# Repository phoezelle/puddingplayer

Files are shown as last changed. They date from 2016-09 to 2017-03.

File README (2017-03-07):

penser à :
passer en azerty + partage ram + …
  raspi-config
ctreate root passwd and log root
  sudo passwd root
update and upgrade apt-get
  apt-get clean
  apt-get update
  apt-get upgrade
install screen
  apt-get screen
install openframworks + script : dependancies.sh + scripts : codecs.sh
  cd /home/pi
  wget http://openframeworks.cc/versions/v0.9.3/of_v0.9.3_linuxarmv6l_release.tar.gz
  mkdir openFrameworks
  tar vxfz of_v0.9.3_linuxarmv6l_release.tar.gz -C openFrameworks --strip-components 1
  cd /home/pi/openFrameworks/scripts/linux/debian
  ./install_dependencies.sh
  ./install_codecs.sh
install wiringpi
  apt-get install wiringPi
install RF24
  $ mkdir nrf24l01
  $ cd nrf24l01
  $ git clone https://github.com/TMRh20/RF24.git
  $ cd RF24
  $ make
  $ sudo make install
compil openframeworks
  make Release -j4 -C /home/pi/openFrameworks/libs/openFrameworksCompiled/project
add my ssh key
  (on my terminal) ssh-copy-id pi@X.X.X.X (IP of pi)
install git-core and clone git repo
  apt-get install git-core
  cd /home/pi/openFrameworks/apps/myApps/
  git clone https://github.com/phoezelle/puddingplayer.git puddingplayer
compil project
  cd puddingplayer/
  make -j4
test it in screen attach mode
  screen -S pudding -m  /home/pi/openFrameworks/apps/myApps/puddingplayer/bin/puddingplayer
create init script
  nano /etc/init.d/puddingplayer
  chmod +x /etc/init.d/puddingplayer
create call script
  nano /etc/init.d/composecall
  chmod +x /etc/init.d/composecall
add call to the script in rc.local
  nano /etc/rc.local
hdmi auto hot plug
  nano /boot/config.txt
définir un réseau de secours
    nano /etc/wpa_supplicant/wpa_supplicant.conf
disable screen saver
    nano /etc/kbd/config
permit root login
    sudo nano /etc/ssh/sshd_config
active spi (dtparam=spi=on)
    sudo nano /boot/config.txt

passer en lecture seule le pi
  http://blog.pi3g.com/2014/04/make-raspbian-system-read-only/

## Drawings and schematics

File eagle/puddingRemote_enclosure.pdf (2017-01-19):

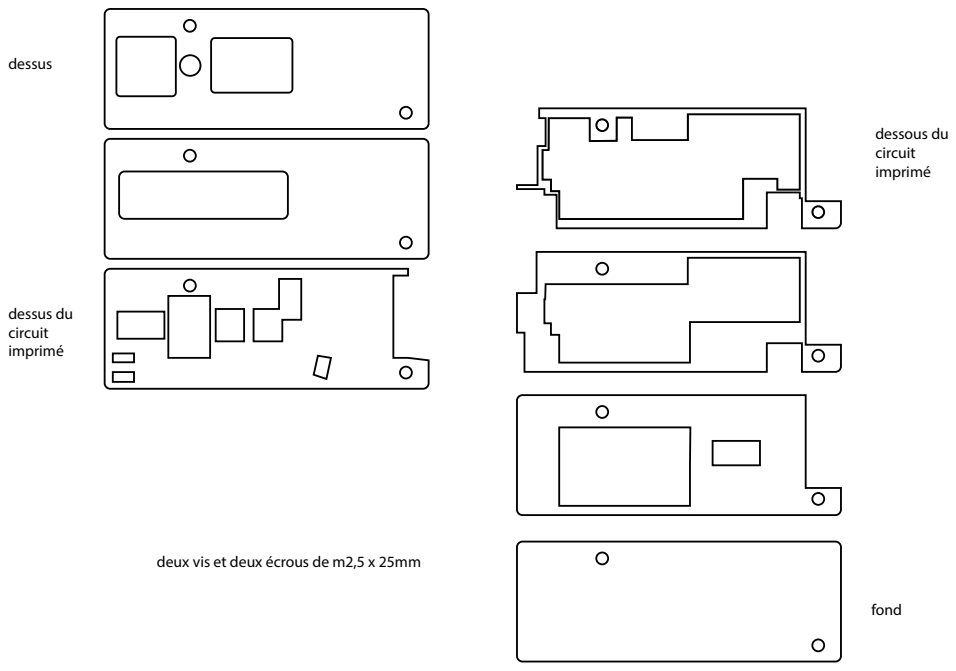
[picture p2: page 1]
dessus; fond; dessus du circuit imprimé; dessous du circuit imprimé

deux vis et deux écrous de m2,5 x 25mm

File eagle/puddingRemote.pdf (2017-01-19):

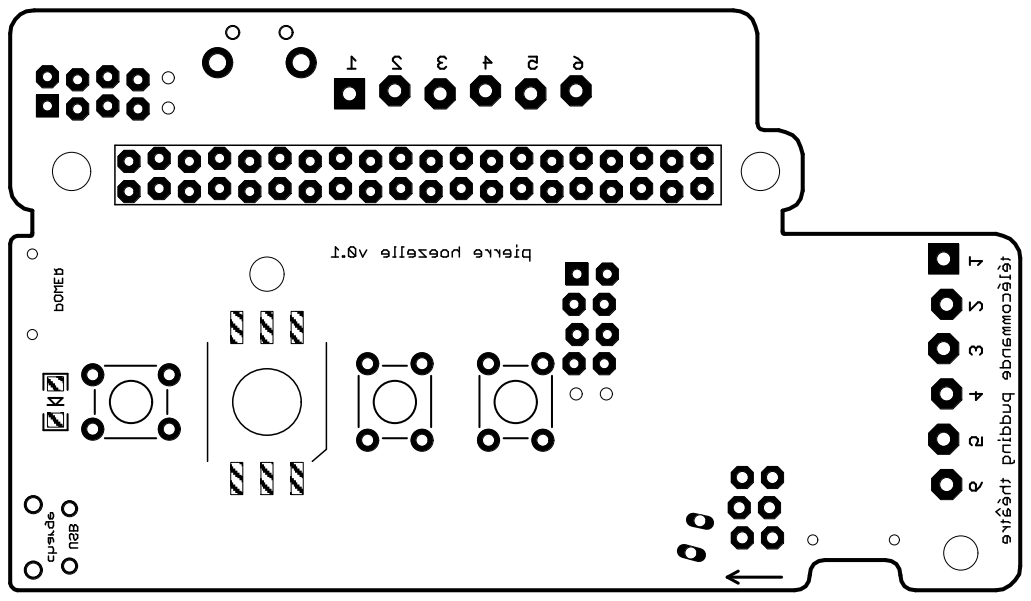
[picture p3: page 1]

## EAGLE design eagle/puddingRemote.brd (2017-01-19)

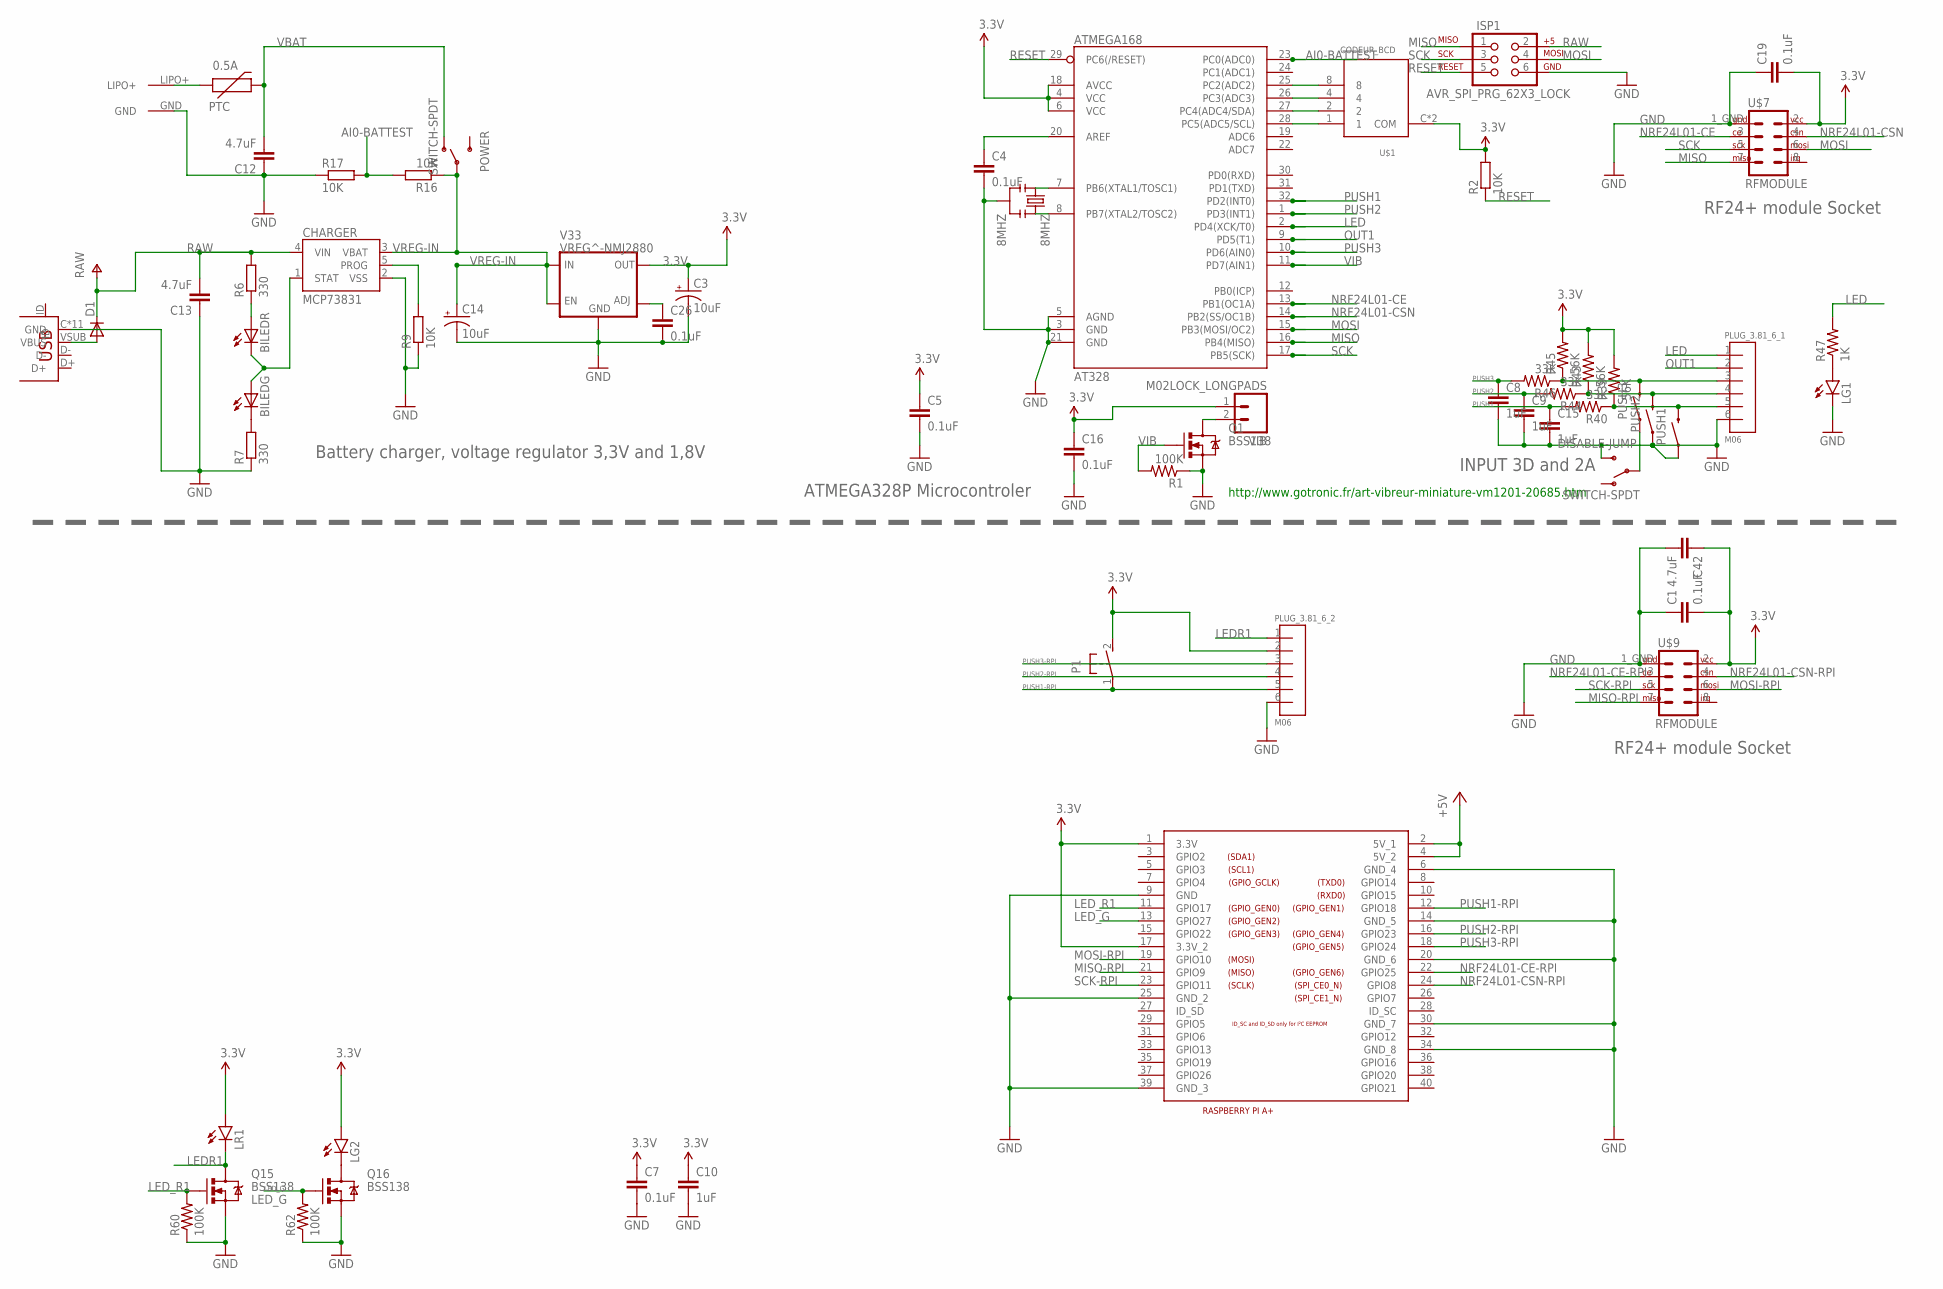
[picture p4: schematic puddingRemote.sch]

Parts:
0.5A: PTC; PTC-1210
8MHZ: 8MHZ; RESONATOR-SMD
AT328: ATMEGA168; TQFP32-08
BILED: BILED; 2XLED
C1, C4, C5, C7, C16, C19, C26: 0.1uF; C0603
C3, C14: 10uF; EIA3216
C8, C9, C10, C15: 1uF; C0603
C12, C13, C42: 4.7uF; C0603
CHARGER: MCP73831; SOT23-5
D1: DIODESMA-KIT; SMA-DIODE-KIT
DISABLE-JUMP: SWITCH-SPDT; SWITCH-102011SAQN
ISP1: AVR_SPI_PRG_62X3_LOCK; 2X3_LOCK
LG1, LG2: LED1206; LED-1206
LR1: LED1206; LED-1206
P1: 31-XX; B3F-31XX
PLUG_3.81_6_1, PLUG_3.81_6_2: M06; PLUG_06
POWER: SWITCH-SPDT; SWITCH-102011SAQN
PUSH1, PUSH2, PUSH3: SWITCH-MOMENTARY-2PTH; TACTILE-PTH
Q1, Q15, Q16: BSS138; SOT23-3
R1, R60, R62: 100K; 0603-RES
R2, R9, R16, R17: 10K; R0603
R6, R7: 330; R0603
R39, R43, R45: 56K; 0603-RES
R40, R44, R46: 33K; 0603-RES
R47: 1K; 0603-RES
U$1: CODEUR_BCD; MCRM4HAF-10R-V-B
U$2: USB-MICROB; USB-MICROB-10103594-0001LF
U$4: RASPIRASPIB; RASPIB
U$7, U$9: RFMODULE; 2X5_RFMODULE
U$8: LIPO_PAD; 2X1_LIPO_PAD
V33: VREG^-NMJ2880; SOT-89
VIB: M02LOCK_LONGPADS; 1X02_LOCK_LONGPADS

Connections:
1: AT328.28 (PC5(ADC5/SCL)), U$1.1
2: AT328.27 (PC4(ADC4/SDA)), U$1.2
3.3V: AT328.4 (VCC), AT328.6 (VCC), AT328.18 (AVCC), C1.2, C3.A (+), C5.1, C7.1, C10.1, C16.1, C19.2, C42.1, LG2.A, LR1.A, P1.2 (S), PLUG_3.81_6_2.2, R2.2, R39.2, R43.2, R45.2, U$1.C (COM), U$1.C2 (COM), U$4.1 (3.3V), U$4.17 (3.3V_2), U$7.2 (VCC), U$9.2 (VCC), V33.4 (OUT), VIB.1
4: AT328.26 (PC3(ADC3)), U$1.4
8: AT328.25 (PC2(ADC2)), U$1.8
+5V: U$4.2 (5V_1), U$4.4 (5V_2)
AI0-BATTEST: AT328.23 (PC0(ADC0)), R16.2, R17.2
AREF: AT328.20 (AREF), C4.1
GND: 8MHZ.2, AT328.3 (GND), AT328.5 (AGND), AT328.21 (GND), C1.1, C3.C (-), C4.2, C5.2, C7.2, C8.2, C9.2, C10.2, C12.1, C13.1, C14.C (-), C15.2, C16.2, C19.1, C26.2, C42.2, CHARGER.2 (VSS), DISABLE-JUMP.3 (S), ISP1.6, LG1.C, PLUG_3.81_6_1.6, PLUG_3.81_6_2.6, PUSH1.1, PUSH2.1, Q1.2 (S), Q15.2 (S), Q16.2 (S), R1.1, R7.1, R9.1, R17.1, R60.1, R62.1, U$2.C (GND), U$2.C1 (GND), U$2.C3 (GND), U$2.C4 (GND), U$2.C5 (GND), U$2.C6 (GND), U$2.GND, U$2.P$1 (GND), U$2.P$2 (GND), U$2.P$3 (GND), U$2.P$4 (GND), U$4.6 (GND_4), U$4.9 (GND), U$4.14 (GND_5), U$4.20 (GND_6), U$4.25 (GND_2), U$4.30 (GND_7), U$4.34 (GND_8), U$4.39 (GND_3), U$7.1_GND (GND), U$8.GND, U$9.1_GND (GND), V33.2 (GND)
LED: AT328.2 (PD4(XCK/T0)), PLUG_3.81_6_1.1, R47.2
LEDR1: LR1.C, PLUG_3.81_6_2.1, Q15.3 (D)
LED_G: Q16.1 (G), R62.2, U$4.13 (GPIO27)
LED_R1: Q15.1 (G), R60.2, U$4.11 (GPIO17)
LG1: LG2.C, Q16.3 (D)
MISO: AT328.16 (PB4(MISO)), ISP1.1, U$7.7 (MISO)
MISO-RPI: U$4.21 (GPIO9), U$9.7 (MISO)
MOSI: AT328.15 (PB3(MOSI/OC2)), ISP1.4, U$7.6 (MOSI)
MOSI-RPI: U$4.19 (GPIO10), U$9.6 (MOSI)
unnamed: C26.1, V33.3 (ADJ)
unnamed: D1.A, U$2.VSUB (VBUS)
unnamed: Q1.3 (D), VIB.2
unnamed: 8MHZ.1, AT328.7 (PB6(XTAL1/TOSC1))
unnamed: 8MHZ.3, AT328.8 (PB7(XTAL2/TOSC2))
unnamed: LG1.A, R47.1
unnamed: DISABLE-JUMP.C, PUSH3.1
unnamed: BILED.A2 (A), R6.1
unnamed: BILED.C3 (C), R7.2
unnamed: CHARGER.5 (PROG), R9.2
NRF24L01-CE: AT328.13 (PB1(OC1A)), U$7.3 (CE)
NRF24L01-CE-RPI: U$4.22 (GPIO25), U$9.3 (CE)
NRF24L01-CSN: AT328.14 (PB2(SS/OC1B)), U$7.4 (CSN)
NRF24L01-CSN-RPI: U$4.24 (GPIO8), U$9.4 (CSN)
OUT1: AT328.9 (PD5(T1)), PLUG_3.81_6_1.2
PUSH1: AT328.32 (PD2(INT0)), C15.1, R40.2
PUSH1-RPI: P1.1, PLUG_3.81_6_2.5, U$4.12 (GPIO18)
PUSH2: AT328.1 (PD3(INT1)), C9.1, R44.2
PUSH2-RPI: PLUG_3.81_6_2.4, U$4.16 (GPIO23)
PUSH3: AT328.10 (PD6(AIN0)), C8.1, R46.2
PUSH3-RPI: PLUG_3.81_6_2.3, U$4.18 (GPIO24)
RAW: C13.2, CHARGER.4 (VIN), D1.C, ISP1.2, R6.2
RESET: AT328.29 (PC6(/RESET)), ISP1.5, R2.1
S1: PLUG_3.81_6_1.5, PUSH1.3 (2), R39.1, R40.1
S2: PLUG_3.81_6_1.4, PUSH2.3 (2), R43.1, R44.1
S3: PLUG_3.81_6_1.3, PUSH3.3 (2), R45.1, R46.1
SCK: AT328.17 (PB5(SCK)), ISP1.3, U$7.5 (SCK)
SCK-RPI: U$4.23 (GPIO11), U$9.5 (SCK)
STAT: BILED.A1 (A), BILED.C4 (C), CHARGER.1 (STAT)
VBAT: 0.5A.2, C12.2, POWER.1 (O)
VBAT-RAW: 0.5A.1, U$8.LIPO+
VIB: AT328.11 (PD7(AIN1)), Q1.1 (G), R1.2
VREG-IN: C14.A (+), CHARGER.3 (VBAT), POWER.C, R16.1, V33.1 (EN), V33.5 (IN)

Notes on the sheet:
RF24+ module Socket
Battery charger, voltage regulator 3,3V and 1,8V
INPUT 3D and 2A
http://www.gotronic.fr/art-vibreur-miniature-vm1201-20685.htm
ATMEGA328P Microcontroler

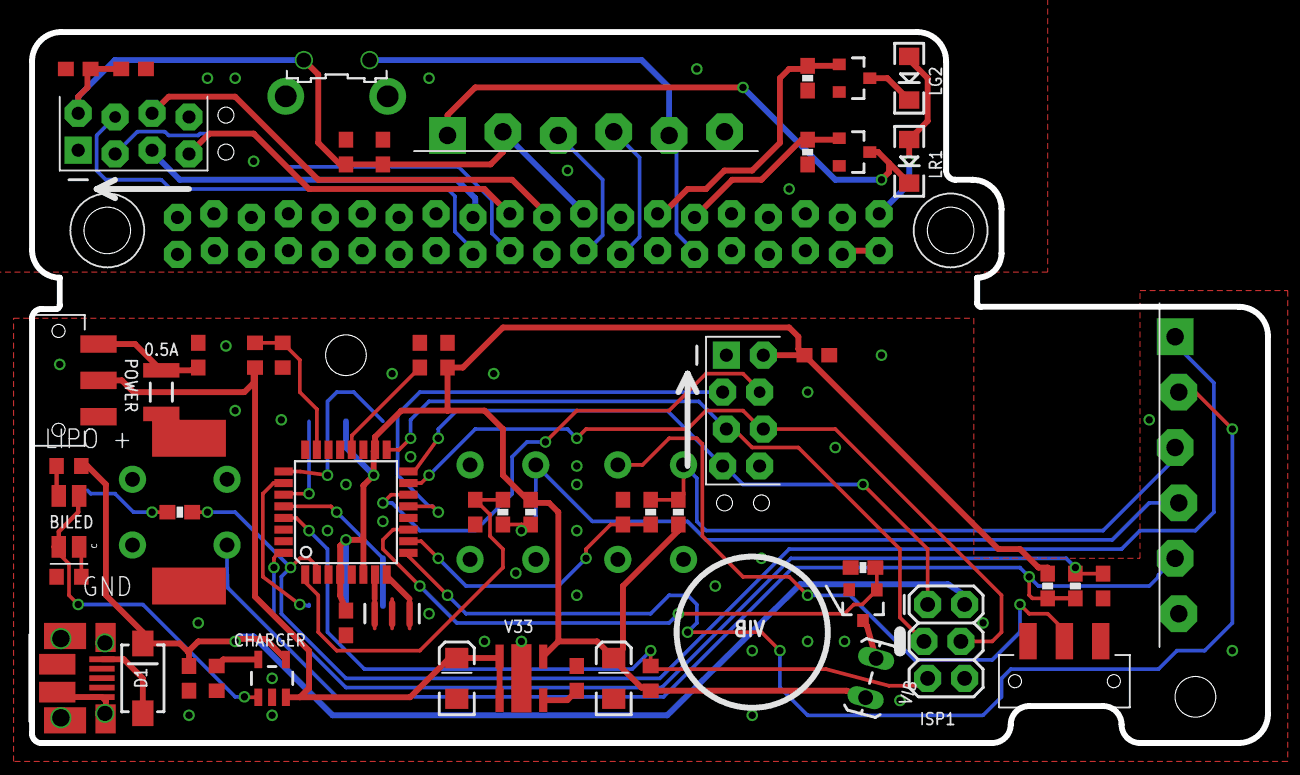
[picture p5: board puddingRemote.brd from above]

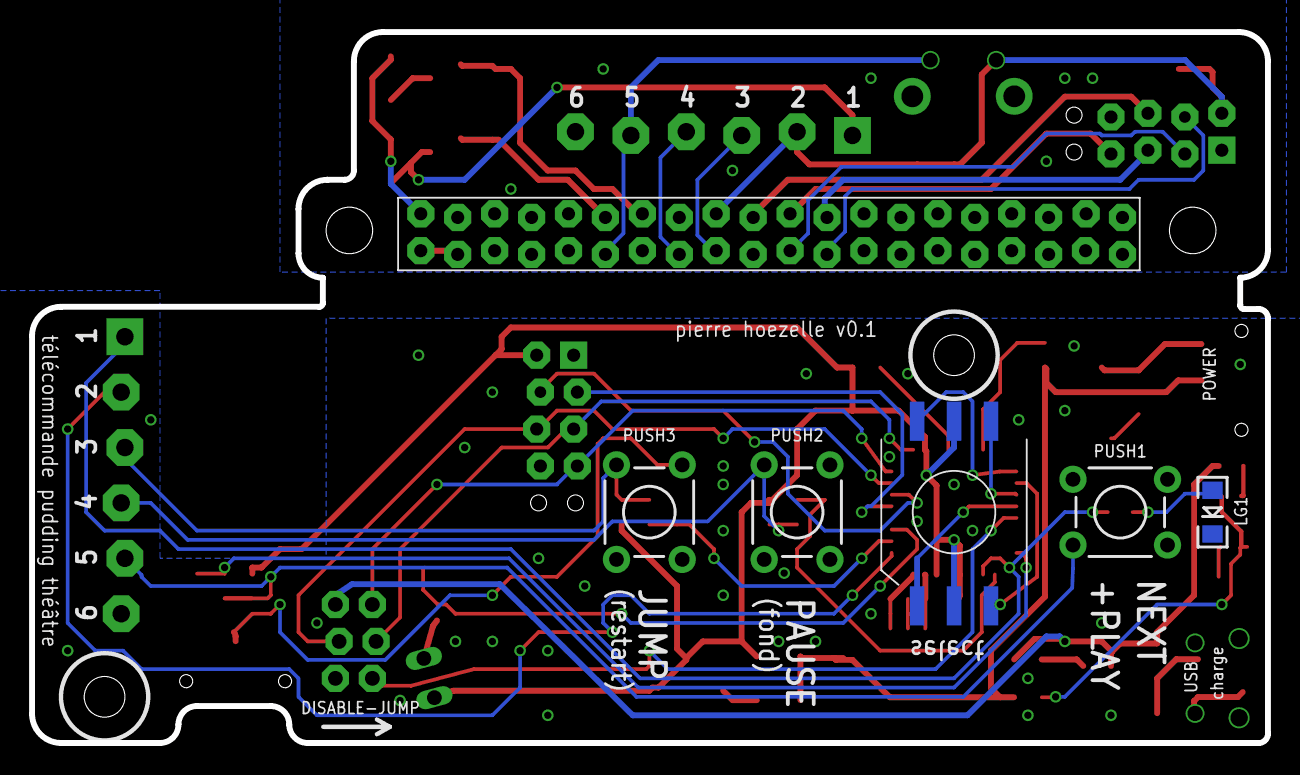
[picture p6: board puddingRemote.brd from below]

Board: 2 copper layers, 85.0 x 48.9 mm, 61 parts (6 on the bottom side), 51 nets.

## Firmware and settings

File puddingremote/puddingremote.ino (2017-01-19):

#include <stddef.h>
#include <avr/pgmspace.h>

#include "nRF24L01.h"
#include "RF24.h"
#include <SPI.h>

#define LED 4
#define VIB 7
#define PUSH1 2
#define PUSH2 3
#define PUSH3 6
#define OUT 5
#define RF24_CE 9
#define RF24_CSN 10
#define MOSI 11
#define MISO 12
#define CLK 13

byte codepin[4]={A2,A3,A4,A5};
byte codevalue[4]={8,4,2,1};


//BATTERY ANALOG CORECTION
#define MASTER_ABATT_5 598
#define MASTER_ABATT_4 589
#define MASTER_ABATT_3 580
#define MASTER_ABATT_2 577
#define MASTER_ABATT_1 564
#define MASTER_ABATT_OFF 540

#define CODE_ACK_WAITING 3
#define CODE_ACK_OK 9
#define CODE_ACK_VALIDATION 5

const uint64_t sendingPrefix = 0xF6FEE60000LL;
RF24 radio(RF24_CE,RF24_CSN);
int channel = 0;

volatile byte p1_state = 0;
volatile byte p2_state = 0;
volatile byte p3_state = 0;

long p1_time_push;
long p2_time_push;
long p3_time_push;

byte p1_long = 0;
byte p2_long = 0;
byte p3_long = 0;
byte p2_superlong = 0;


byte vib_value = LOW;
byte vib_state = 0;
long vib_time_on = millis();
int vib_time_period = 50;

byte led_state = 0;
byte led_value = LOW;
long led_time_on = millis();
int led_time_period = 200;

byte needcheckbatterie = 0;

long speeddown =1;
byte startup = 1;


void setup() {
  //init serial
  Serial.begin(115200);
  Serial.print("start pudding remote");
  
  //pin mode
  pinMode(LED, OUTPUT);
  pinMode(VIB, OUTPUT);
  pinMode(RF24_CE, OUTPUT);
  pinMode(RF24_CSN, OUTPUT);
  pinMode(PUSH1, INPUT);
  pinMode(PUSH2, INPUT);
  pinMode(PUSH3, INPUT);
  for(byte i=0;i<4;i++){
    pinMode(codepin[i],OUTPUT);
    digitalWrite(codepin[i],LOW);
    pinMode(codepin[i],INPUT);
  }
  

  //init radio
  radio.begin();
  radio.setRetries(1,6); // 6 try delay 500us each
  radio.setPayloadSize(8);
  radio.enableAckPayload();
  radio.setChannel(122);
  //radio.setDataRate(RF24_250KBPS);
  radio.setPALevel(RF24_PA_MAX);
  radio.stopListening();
  if (radio.isPVariant()) Serial.print("radio OK ");
  
  delay(200);
  //get remote channel
  for(byte i=0;i<4;i++){
    byte count = 0;
    for(byte j=0;j<10;j++){
      if(digitalRead(codepin[i])==HIGH) count++;
      delay(1);
    }
    Serial.print(codepin[i],DEC);
    Serial.print(":");
    Serial.print(count,DEC);
    Serial.print(" ");
    if(count==10) channel+=codevalue[i];
  }
  
  Serial.print("ch");
  Serial.print(channel,DEC);
  updateSendingAddress(channel);
  flash_led(channel);

  //interrupt for two first push
  attachInterrupt(0, p1, CHANGE);
  attachInterrupt(1, p2, CHANGE);

  getBatteryStatus();
  flash_vib(1);
  
}

void slowdown(){
  CLKPR = 0x80;    // Tell the AtMega we want to change the system clock
  CLKPR = 0x05;    // 1/32 prescaler = 250KHz for a 16MHz crystal
  speeddown = 32;
}

void speedup(){
      CLKPR = 0x80;    // Tell the AtMega we want to change the system clock
      CLKPR = 0x0;
      speeddown =1;
}

long myTime (long t){
  return (long)(1.0f*t)/speeddown;
}

void loop() {
  // put your main code here, to run repeatedly:
  if(p1_state==1){
    Serial.print("p1p");
    p1_time_push=millis();
    p1_state++;
  }
  if(!p1_long && p1_state==2 && millis()-p1_time_push>myTime(2000)){
    Serial.print("p1l");
    p1_long=1;
    flash_led(1);
  }
  if(p2_state==1){
    Serial.print("p2p");
    p2_time_push=millis();
    p2_state++;
  }
  if(!p2_superlong && !p2_long && p2_state==2 && millis()-p2_time_push>myTime(2000)){
    Serial.print("p2l");
    p2_long=1;
    flash_led(1);
  }
  if(!p2_superlong && p2_state==2 && millis()-p2_time_push>myTime(10000)){
    Serial.print("p2sl");
    p2_superlong=1;
    p2_long=0;
    flash_led(3);
  }
  if(p1_state==3){
    Serial.print("p1r");
    if(p1_long==0){sendMessage(1); }else{ sendMessage(2); }
    p1_state=0;p1_long=0;
  }
  if(p2_state==3){
    Serial.print("p2r");
    if(p2_superlong==1){ sendMessage(8); }else{
      if(p2_long==0){ sendMessage(3); }else{ sendMessage(4); }
    }
    p2_state=0;p2_long=0;p2_superlong=0;
  }

  
  if((p3_state==0 && !digitalRead(PUSH3)) || (p3_state==2 && digitalRead(PUSH3))){
    if(p3_state==0)p3_state=1;
    if(p3_state==2)p3_state=3;
  }
  if(p3_state==1){
    Serial.print("p3p");
    p3_time_push=millis();
    p3_state++;
  }
  if(!p3_long && p3_state==2 && millis()-p3_time_push>myTime(2000)){
    Serial.print("p3l");
    p3_long=1;
    flash_led(1);
  }
  if(p3_state==3){
    Serial.print("p3r");
    if(p3_long==0){ sendMessage(5); }else{ sendMessage(6); }
    p3_state=0;p3_long=0;
  }
  
  if(led_state > 0 && millis() - led_time_on > myTime(led_time_period)){
    Serial.print("led");Serial.print(led_state,DEC);Serial.print("-");Serial.print(led_value,DEC);
    led_time_on = millis();
    led_state--;
    led_value = !led_value;
    digitalWrite(LED, led_value);
  }
  if(led_state==0){
    led_value=0;
    digitalWrite(LED, led_value);
  }
  
  if(vib_state > 0 && millis() - vib_time_on > myTime(vib_time_period)){
    Serial.print("vib");Serial.print(vib_state,DEC);
    vib_time_on = millis();
    vib_state--;
    vib_value = !vib_value;
    digitalWrite(VIB, vib_value);
  }
  if(vib_state==0){
    vib_value=0;
    digitalWrite(VIB, vib_value);
  }

 if(needcheckbatterie==1){
  if(millis()%myTime(1000)>myTime(700)){
  needcheckbatterie=0;
  getBatteryStatus();
  }
 }
  if(needcheckbatterie==0){
  if(millis()%myTime(1000)<myTime(200))needcheckbatterie=1;
 }

 if(startup==1 ){
  if(millis()>myTime(10000)){startup=0;
  slowdown();
  }
 }
  
}



void p1()
{
  //Serial.print("p1");
  if(p1_state==0)p1_state=1;
  if(p1_state==2)p1_state=3;
}
void p2()
{
  //Serial.print("p2");
  if(p2_state==0)p2_state=1;
  if(p2_state==2)p2_state=3;
}

void updateSendingAddress(byte suffix){
    uint64_t address = sendingPrefix | suffix;
    radio.openWritingPipe(address);
}

void sendMessage(int tmessage){
  /*if(sendMessageProc(tmessage)){
    sendMessageProc(9);
  }*/
  speedup();
  delay(1);
  radio.powerUp();
  delay(10);
  if(sendMessageSimple(tmessage)){
    sendMessageSimple(9);
  }
  radio.powerDown();
}

bool sendMessageProc(int tmessage){
  uint64_t message=0x0000000000LL;
  message |= tmessage;
  byte noConnect=0;
  while(1){
  Serial.print ("send ");Serial.print (tmessage);
  boolean connect = radio.write(&message, sizeof(message));
  byte result = 0;
  if(connect){
     if (radio.isAckPayloadAvailable()) {
        uint64_t received=0;
        radio.read(&received, sizeof(received));
        result=lowByte(received)&0x0F;
        Serial.print ("ack");Serial.print (result,DEC);
        }
      }
   switch (result) {
    case CODE_ACK_WAITING :
      Serial.print ("SEND-OK");
    break;
    case CODE_ACK_OK :
       Serial.print ("SEND-ENDING");
       if(tmessage>0 && tmessage<9)flash_vib(2);  
       //flush ack
       return true;
    break;
    default:
    noConnect++;
    if(noConnect>20){
       Serial.print ("SEND-ABORT");
       return false;
    }
   }
  }
}

bool sendMessageSimple(int tmessage){
  uint64_t message=0x0000000000LL;
  message |= tmessage;
  byte noConnect=0;
  while(1){
  Serial.print ("send ");Serial.print (tmessage);
  boolean connect = radio.write(&message, sizeof(message));
  if(connect){
     byte result = 0;
     if (radio.isAckPayloadAvailable()) {
        uint64_t received=0;
        radio.read(&received, sizeof(received));
        result=lowByte(received)&0x0F;
        Serial.print ("ack");Serial.print (result,DEC);
        if (result==tmessage){
          flash_vib(2);
          return true;
          
          }
        }
  }
    noConnect++;
    if(noConnect>20){
       Serial.print ("SEND-ABORT");
       return false;
    }
   }
  
}

void flash_led(byte f){
  Serial.print ("startflashled");Serial.print(f,DEC);
  led_state=2*f;
}

void flash_vib(byte f){
  Serial.print ("startflashvib");Serial.print(f,DEC);
  vib_state=2*f;
}


// *************************************************************************************
//          card utility
// *************************************************************************************

int getAnalogBatteryValue(){
  int bat = analogRead(A0);
  Serial.print("b");
  Serial.print(bat,DEC);
  return bat;
}

byte getBatteryStatus() {
  int bat = getAnalogBatteryValue();
  if (bat > MASTER_ABATT_5)
    return 5;
  if (bat > MASTER_ABATT_4)
    return 4;
  if (bat > MASTER_ABATT_3)
    return 3;
  if (bat > MASTER_ABATT_2)
    return 2;
  if (bat > MASTER_ABATT_1)
    flash_led(2);
    return 1;
  if (bat < MASTER_ABATT_OFF)
    flash_led(2);
    return 255;
  return 0;
}

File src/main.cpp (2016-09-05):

#include "ofMain.h"
#include "ofApp.h"

//========================================================================
int main( ){
  
	ofSetupOpenGL(1920 ,1280, OF_WINDOW);			// <-------- setup the GL context
  
  ofGLESWindowSettings settings;
  settings.setGLESVersion(2);
  ofCreateWindow(settings);
  ofRunApp(new ofApp);
}

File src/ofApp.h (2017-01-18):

#pragma once

#include "ofMain.h"
#include "checkremote.h"


class ofApp : public ofBaseApp{
  
public:
  
  Checkremote thread;
  
  void setup();
  void update();
  void draw();
  void exit();
  
  void keyPressed(int key);
  void keyReleased(int key);
  void mouseMoved(int x, int y );
  void mouseDragged(int x, int y, int button);
  void mousePressed(int x, int y, int button);
  void mouseReleased(int x, int y, int button);
  void mouseEntered(int x, int y);
  void mouseExited(int x, int y);
  void windowResized(int w, int h);
  void dragEvent(ofDragInfo dragInfo);
  void gotMessage(ofMessage msg);
  
  //SETUP AND PREF
  void definePlateform();
  void usbstickMount();
  void buildMediaList();
  void getPref();
  void checkNetwork();
  void setcurrentCharacter(int _character);
  
  bool pi,firstlaunch;
  int posX,posY,width,height,loglevel;
  string firstMessage;
  vector <string> characterList;
  vector <vector <string>> mediaList;
  vector <string> backgroundList;
  
  //GPIO
  void initGPIO();
  void checkGPIO();
  void getAnalogBattery();
  
  void checkREMOTE();
  
  int ledG_value;
  int ledG_state;
  uint64_t ledG_time_on;
  uint64_t ledG_time_period;
  
  int ledR_state;
  int ledR_value;
  uint64_t ledR_time_on;
  uint64_t ledR_time_period;
  //ofThreadChannel<int> myThreadChannel;
  void checkLed();
  void flash_ledG(int f);
  void flash_ledR(int f);
  

#define PIN_NUM 3
#define PUSH1 1
#define PUSH2 4
#define PUSH3 5

#define LEDR 0
#define LEDG 2
  
  
  int laststate[PIN_NUM];
  int pin[PIN_NUM];
  uint64_t startpushtime[PIN_NUM];
  bool longpush[PIN_NUM];
  

  
  //VIDEOPLAYER
  ofVideoPlayer 		*fingerMovie;
  ofVideoPlayer     *fingerMovie2;
  int nvideo;
  int gochangevideo;
  bool isplayground;
  void play();
  void playNext();
  void pausePlay();
  void playBackground();
  void changeBackground();
  void nextScene();
  void restartScene();
  void clearVideo(int n);
  
  int maxScene, currentScene, currentVideo, currentBackground, currentCharacter,nbMedia;
  string rootDirectory,mediaDirectory,backgroundDirectory;
  
  //UTILITY
  void log(string log,int level,bool color=false);
  
#define WARNING 0
#define USR 1
#define DEBUG 2
#define RAW 3
  

  
  //void checkinputandplayVideo();
  //void playVideoInPath();
  
  
  
  
  
  
};

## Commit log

2016-09-01 first commit2
    [config.txt]
2016-09-01 first commit3
    [config.txt]
2016-09-01 good pin number
2016-09-01 test another pin than I2C
2016-09-01 try avoid green flaw
    [ofApp.cpp]
2016-09-02 add 3 pin (wiring pi 0 2 3) (bcm 17 27 22) and long push mechanism
2016-09-05 try correct last video bug
    [ofApp.cpp]
2016-09-05 correct duplicate first video in medialist of new scene
    [ofApp.cpp]
2016-09-05 another little bug : restart at the beginning and do not iterate
    [ofApp.cpp]
2017-01-13 test spi
2017-01-17 add thread
2017-01-17 add call the thread
2017-01-17 do not use thread channel
2017-01-18 fix led
2017-01-19 add eagle + arduino manque sender
    [puddigDCconverterNotUse.sch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]
2017-03-07 add scipt file for rpi
    [config.txt]

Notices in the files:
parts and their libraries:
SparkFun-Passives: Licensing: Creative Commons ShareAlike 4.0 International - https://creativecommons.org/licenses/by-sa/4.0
